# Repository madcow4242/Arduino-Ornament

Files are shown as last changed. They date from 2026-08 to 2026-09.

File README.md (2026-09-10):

# Arduino-powered Christmas Ornament (or badge, or anything else)

A custom LED Christmas ornament with advent calendar functionality, built using Arduino and KiCad.  This project can easily be adapted to other formats such as a badge by changing the PCB layout.  

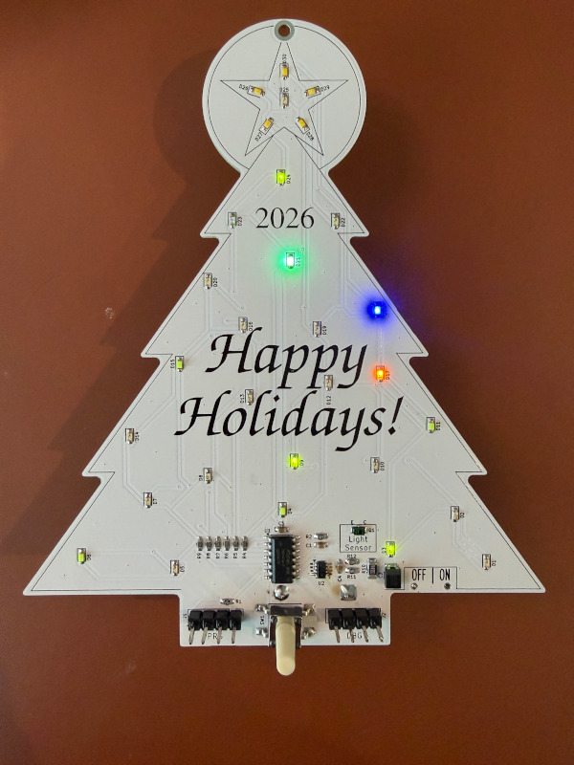
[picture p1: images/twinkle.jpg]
Example Ornament


### Key features:
- 30 individually-addressable LEDs
- PWM LED control, with support for up to 12 (or more) simultaneous LEDs
- Fade-in / Fade-out support
- Advent calendar mode included
- User-configurable advent date and brightness settings
- Light level measurement (optional)
- Current measurement via a precision 1-ohm current sense resistor and precision amplified ADC circuit (intended to help optimize power usage prior to software finalization) (optional)
- Optimized to fit within the 4k / 256 byte memory limitations of the ATTiny414, but is also compatible with larger variants such as the ATTiny 814/1614/824/1624/3224
- Production software is configured to run at 8MHz to optimize power usage (instead of default 20MHz) - this can be changed if higher PWM frequency is desired, for example.  (test software still runs at 20MHz)
- \>30 days run time on one set of 3x AAA batteries, using default Production software (5 hours/day on, with auto timer).  Can be run on other 3-5VDC power sources like CR2032 for shorter durations (however, \>3.5V is required for 2.8V LEDs or higher - so stick with ~2.2V LEDs or lower if using 3-3.3V power sources).

## Project Structure

This project is organized into three main directories:

### 1. KiCad Files (`KiCad_PCB_Ornament/`)
Contains all KiCad design files for the PCB:
- Schematic files (.kicad_sch)
- PCB layout files (.kicad_pcb)
- Component libraries (.lib, .dcm)
- Footprint files (.kicad_mod)
- Exported fabrication files (.gbr, .drl) (for the example design / messaging)

The PCB layout can be easily customized with your own text, or into a different physical format or size (like a badge) using KiCad - however if modifying the layout you'll have to re-route the board as well of course.  I chose to put the control electronics on the front of the board (to be geeky), but they could easily be moved to the back to clean up the appearance.

NOTE: the board design includes optional current monitoring circuit and light sensing circuit.  Neither of these are implemented in the production software, however they are fully functional and usable in the test software.  Those features can be ported to production as needed, or removed or unpopulated on the PCB.

### 2. Production Software (`Ornament_production_1/`)
The main firmware for the ornament controller:
- Main Arduino sketch (`Ornament_production_1.ino`)
- Configuration and constants
- LED control algorithms
- Date setting and brightness adjustment routines
- Software fits in under 4k of flash, and uses approx. 70 (of 256) bytes of dynamic storage

### 3. Test/Validation Software (`Ornament_test_1/`)
Code for testing and validating the PCB functionality:
- Calibration routines
- Basic functionality tests
- Hardware verification code
- Software uses less than the ATTiny414's 4k of flash and 256 bytes of dynamic storage
- Includes ADC routines for current monitoring and light level measurement, if needed (not used in production code)

## Production Features

- Advent calendar display (December 1-25)
- Custom LED patterns with twinkling effects, including PWM fade-in, fade-out
- Date setting via button interface
- Adjustable brightness levels (10% to 100%)
- Sleep/wake cycle automation
- Preview mode for manual activation during sleep, without affecting 24-hour auto-on timer

## Hardware Requirements

- Microchip ATtiny414 microcontroller (or others in that series)
- Custom PCB with LED matrix
- Power switch and button for user interface
- Battery or power supply for operation
- Optional serial monitor to view diagnostic output on the UART connections (test software only by default)

## Getting Started

1. Clone this repository
2. Open the KiCad project to view or modify the PCB design
3. Use the Arduino IDE to compile and upload the production firmware to the completed PCB
4. Test with the validation software to verify hardware functionality
5. Modify and install the production software as desired

## License

This project is licensed under the MIT License - see the LICENSE file for details.

## Notes

- Custom LCG (Linear Congruential Generator) for random number generation to save flash space
- Charlieplexing technique for LED control - it uses 6 GPIOs to allow individual addressability for up to 30 LEDs.
- PWM LED control for up to 12 LEDs simultaneously, using 3x 32-step groups for each PWM cycle (4 LEDs per cycle)
- (more LEDs can be controlled simultaneously via configuration, but will limit maximum LED brightness)

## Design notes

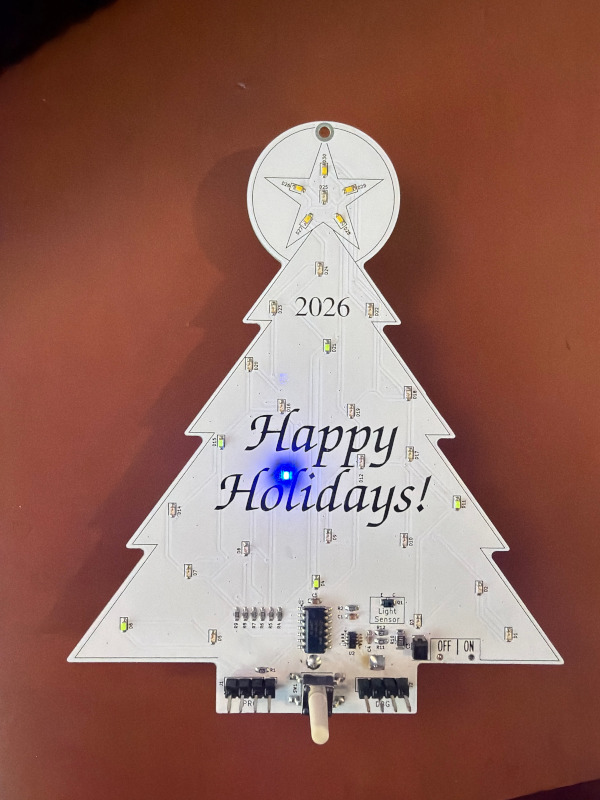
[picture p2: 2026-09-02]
images/adventday.jpg

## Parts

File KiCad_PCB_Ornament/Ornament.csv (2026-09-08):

Reference | Qty | Value | DNP | Exclude from BOM | Exclude from Board | Footprint | Datasheet | Mouser link | $ qty 1 | $ qty 25 | $ qty 100
BT1 | 1 | Battery_Holder |  |  |  | CustomLibrary:BatteryHolder_Keystone_2479_3xAAA-NoHoles | https://www.mouser.com/datasheet/3/201/1/2479.pdf | https://www.mouser.com/en/ProductDetail/Keystone-Electronics/2479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 | 1.8 | 1.6 | 1.58
C1 | 1 | C10nF |  |  |  | Capacitor_SMD:C_0603_1608Metric_Pad1.08x0.95mm_HandSolder | https://www.mouser.com/datasheet/3/72/1/C0603F103K9RACTU.pdf | https://www.mouser.com/en/ProductDetail/KEMET/C0603F103K9RACTU?qs=6avfeC6zeS4aPXDpR2QexA%3D%3D | 0.17 | 0.102 | 0.062
C3 | 1 | C220uF or 470uF low-ESR Polymer or Tantalum |  |  |  | Capacitor_SMD:C_1210_3225Metric_Pad1.33x2.70mm_HandSolder | https://www.mouser.com/datasheet/3/5926/1/TCJ.pdf | https://www.mouser.com/en/ProductDetail/KYOCERA-AVX/TCJB227M004R0060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 | 1.44 | 1 | 0.74
C4 | 1 | C1nF | Optional (Current Sense) |  |  | Capacitor_SMD:C_0603_1608Metric_Pad1.08x0.95mm_HandSolder | https://datasheets.kyocera-avx.com/AutoMLCC.pdf | https://www.mouser.com/en/ProductDetail/KYOCERA-AVX/06031F102K4T2A?qs=%252BdQmOuGyFcFZxL9GWikwcQ%3D%3D | 0.14 | 0.079 | 0.048
C5 | 1 | C1uF |  |  |  | Capacitor_SMD:C_0603_1608Metric_Pad1.08x0.95mm_HandSolder | https://ds.yuden.co.jp/TYCOMPAS/ut/download?pn=MSASE168SB5105KTNA01&fileType=CS | https://www.mouser.com/en/ProductDetail/TAIYO-YUDEN/MSASG168SB5105KTNA01?qs=yc9RBI4tIALTzUyUX1jaSQ%3D%3D | 0.17 | 0.073 | 0.042
D25 | 1 | LED - RED |  |  |  | LED_SMD:LED_0603_1608Metric_Pad1.05x0.95mm_HandSolder | https://www.mouser.com/datasheet/3/308/1/APG1608SURKC_T.pdf | https://www.mouser.com/en/ProductDetail/Kingbright/APG1608SURKC-T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 | 0.23 | 0.155 | 0.109
D26,D27,D28,D29,D30 | 5 | LED - WHITE |  |  |  | LED_SMD:LED_0603_1608Metric_Pad1.05x0.95mm_HandSolder | https://www.mouser.com/datasheet/3/5912/1/LW_Q38G_EN.pdf | https://www.mouser.com/en/ProductDetail/ams-OSRAM/LW-Q38G-Q2OO-3K5L-1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 | 0.58 | 0.35 | 0.139
D3,D9,D14,D19,D24 | 5 | LED - GREEN |  |  |  | LED_SMD:LED_0603_1608Metric_Pad1.05x0.95mm_HandSolder | https://www.mouser.com/datasheet/3/308/1/APG1608CGKC_T.pdf | https://www.mouser.com/en/ProductDetail/Kingbright/APG1608CGKC-T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 | 0.23 | 0.155 | 0.109
D2,D8,D13,D18,D23 | 5 | LED - BLUE |  |  |  | LED_SMD:LED_0603_1608Metric_Pad1.05x0.95mm_HandSolder | https://www.mouser.com/datasheet/3/308/1/APTD1608LVBC_D.pdf | https://www.mouser.com/en/ProductDetail/Kingbright/APTD1608LVBC-D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 | 0.58 | 0.408 | 0.294
D4,D6,D11,D15,D21 | 5 | LED - CYAN |  |  |  | LED_SMD:LED_0603_1608Metric_Pad1.05x0.95mm_HandSolder | https://www.mouser.com/datasheet/3/308/1/APT1608VRCXF_A_5MAV.pdf | https://www.mouser.com/en/ProductDetail/Kingbright/APT1608VRCXF-A-5MAV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 | 0.72 | 0.499 | 0.363
D1,D7,D12,D17,D22 | 5 | LED - YELLOW |  |  |  | LED_SMD:LED_0603_1608Metric_Pad1.05x0.95mm_HandSolder | https://www.mouser.com/datasheet/3/308/1/APG1608SYKC_T.pdf | https://www.mouser.com/en/ProductDetail/Kingbright/APG1608SYKC-T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 | 0.23 | 0.155 | 0.109
D5,D10,D16,D20 | 4 | LED - ORANGE |  |  |  | LED_SMD:LED_0603_1608Metric_Pad1.05x0.95mm_HandSolder | https://www.mouser.com/datasheet/3/308/1/APG1608SEKC_T.pdf | https://www.mouser.com/en/ProductDetail/Kingbright/APG1608SEKC-T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 | 0.23 | 0.155 | 0.109
H1 | 1 | MountingHole |  | Excluded from BOM |  | MountingHole:MountingHole_2.2mm_M2_DIN965_Pad_TopBottom | N/A | N/A
H2 | 1 | QR Code (silkscreen) |  | Excluded from BOM |  | CustomLibrary:15mmQR_cazabon_ornament | N/A | N/A
J1,J2 | 2 | Conn_01x04_Pin |  |  |  | Connector_PinHeader_2.54mm:PinHeader_1x04_P2.54mm_Vertical | https://cdn.amphenol-cs.com/media/wysiwyg/files/drawing/68000.pdf | https://www.mouser.com/en/ProductDetail/Amphenol-FCI/68004-404HLF?qs=iiM6sTJtPEeXIoTTLP40zg%3D%3D | 0.29 | 0.216 | 0.188
Q1 | 1 | TEMT6200FX01 | Optional (Light Sensor) |  |  | Resistor_SMD:R_0805_2012Metric_Pad1.20x1.40mm_HandSolder | https://www.rcscomponents.kiev.ua/datasheets/bpw40.pdf | https://www.mouser.com/en/ProductDetail/Vishay-Semiconductors/TEMT6200FX01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 | 0.76 | 0.643 | 0.614
R1 | 1 | R4.7k |  |  |  | Resistor_SMD:R_0603_1608Metric_Pad0.98x0.95mm_HandSolder | https://www.mouser.com/datasheet/3/508/1/PYu-RP_51_RoHS_L_3.pdf | https://www.mouser.com/en/ProductDetail/YAGEO/RP0603FRE074K7L?qs=Y0Uzf4wQF3kHfBhD8kHClQ%3D%3D | 0.1 | 0.049 | 0.047
R2 | 1 | R10k | Optional (Light Sensor) |  |  | Resistor_SMD:R_0603_1608Metric_Pad0.98x0.95mm_HandSolder | https://www.mouser.com/datasheet/3/72/1/PYU_RT_1_TO_0_01_ROHS_L.pdf | https://www.mouser.com/en/ProductDetail/YAGEO/RT0402FRE1310KL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 | 0.1 | 0.013 | 0.012
R4,R5,R6,R7,R8,R9 | 6 | R82 |  |  |  | Resistor_SMD:R_0603_1608Metric_Pad0.98x0.95mm_HandSolder | https://www.mouser.com/datasheet/3/72/1/PYU_RT_1_TO_0_01_ROHS_L.pdf | https://www.mouser.com/en/ProductDetail/YAGEO/RT0603BRD0782RL?qs=%2Ff7pOCXLR5eRsjR2nYqoNw%3D%3D | 0.1 | 0.06 | 0.056
R10 | 1 | R1 | R0 if no current sense |  |  | Resistor_SMD:R_1206_3216Metric | https://www.koaspeer.com/pdfs/SR73.pdf | https://www.mouser.com/en/ProductDetail/KOA-Speer/SR732BTTD1R00D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 | 0.53 | 0.228 | 0.205
R11,R12 | 2 | R100 | Optional (Current Sense) |  |  | Resistor_SMD:R_0603_1608Metric_Pad0.98x0.95mm_HandSolder | https://www.mouser.com/datasheet/3/508/1/PYU_RP_51_ROHS_L.pdf | https://www.mouser.com/en/ProductDetail/YAGEO/RP0603FRE07100RL?qs=Y0Uzf4wQF3lM9ZFwqInEig%3D%3D | 0.1 | 0.049 | 0.047
SW1 | 1 | SW_Push |  |  |  | Button_Switch_SMD:SW_Push_1P1T_NO_E-Switch_TL3301NxxxxxG | https://www.te.com/commerce/DocumentDelivery/DDEController?Action=srchrtrv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 | https://www.mouser.com/en/ProductDetail/TE-Connectivity-PB/1571563-6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 | 0.51 | 0.456 | 0.405
SW2 | 1 | SW_SPDT |  |  |  | Switch:CSS1210TB | https://www.nidec-copal-electronics.com/e/catalog/switch/css.pdf | https://www.mouser.com/en/ProductDetail/Nidec-Components/CSS-1210TB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 | 0.72 | 0.577 | 0.515
U1 | 1 | ATtiny414-SS (814,1614,424,824,1624,3224) |  |  |  | Package_SO:SOIC-14_3.9x8.7mm_P1.27mm | http://ww1.microchip.com/downloads/en/DeviceDoc/40001912A.pdf | https://www.mouser.com/en/ProductDetail/Microchip-Technology/ATTINY414-SSF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 | 0.68 | 0.62 | 0.619
U2 | 1 | INA190A3IDDFR | Optional (Current Sense) |  |  | Package_TO_SOT_SMD:SOT-23-8_Handsoldering | https://www.ti.com/lit/gpn/ina190 | https://www.mouser.com/en/ProductDetail/Texas-Instruments/INA190A3IDDFR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 | 2.34 | 1.59 | 1.42
 |  |  |  |  |  |  |  | BOM Cost | 24.92

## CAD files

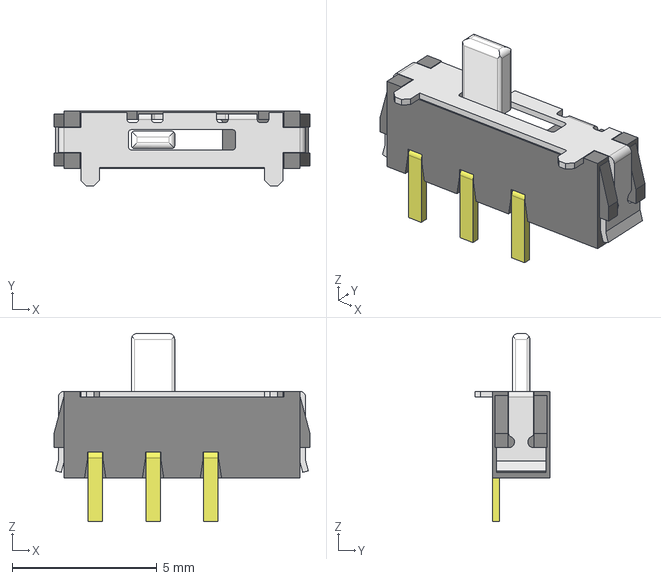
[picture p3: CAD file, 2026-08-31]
KiCad_PCB_Ornament/LIB_CSS-1210TB/CSS-1210TB/3D/CSS-1210TB.stp
8.85 x 2.60 x 6.50 mm
CSS-1210TB-b
CSS-1210TB-s

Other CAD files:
KiCad_PCB_Ornament/LIB_CSS-1210TB/CSS-1210TB/Allegro/css1210tb.psm
KiCad_PCB_Ornament/LIB_CSS-1210TB/CSS-1210TB/DEHDL/css_1210tb/chips/chips.prt

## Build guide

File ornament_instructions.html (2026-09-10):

# Ornament Controller Instructions

User Guide for the Custom LED Ornament

## Turning the Ornament On

1. Install 3x AAA batteries in the battery holder on the back of the ornament - with the negative (flat) side facing the spring in each compartment. (A fresh set of quality batteries should last ~30 days in normal operation with default brightness)

2. Locate the power switch on the right-hand side of the ornament, on the underside of the branches.

3. Slide the switch to the "on" position. Ideally, do this at the time you want the ornament to start its daily cycle.

4. The ornament will immediately begin operating in its default mode, alternating between "twinkling" and showing the advent calendar display.

5. The ornament will run for 5 hours from when you turned it on, then sleep until 24 hours after the initial powering-on and continue in that cycle. The result is that it will auto-activate at the same time each day, and run for 5 hours before going to sleep until the next day.

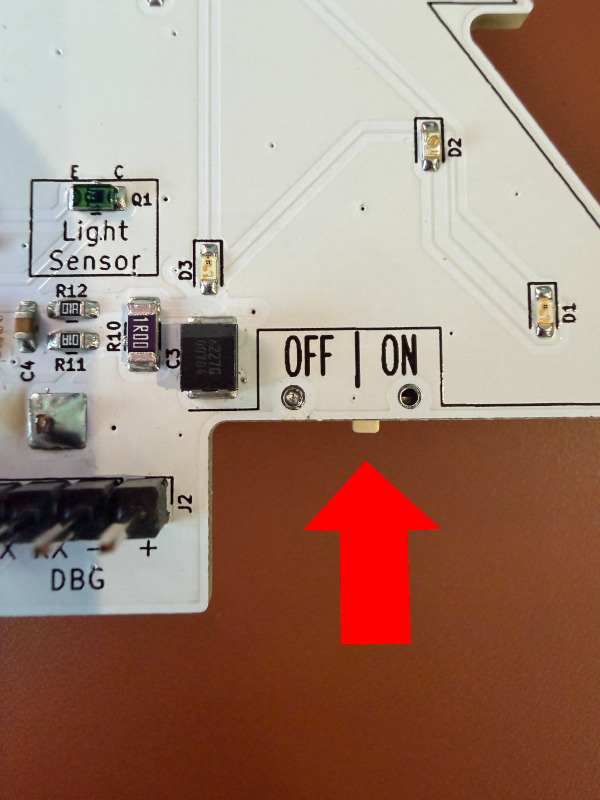
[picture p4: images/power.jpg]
Power Button Location


Figure 1: Power Button Location

## Setting the Daily Start Time

1. The ornament will automatically start each day at the same time, based on when you initially turn it on, or when power was most recently restored.

2. To set or re-set the start time, simply turn the ornament off by the switch (or remove the batteries), leave it off for at least 30 seconds, then turn it back on at the time you want it to start each day.

3. The ornament will now use this time as the daily start time.

4. There is no need to turn the ornament off or on each day - it will automatically cycle for 5 hours on daily, and will run for >30 days on a fresh set of AAA batteries.

5. Using the 'Preview Mode' (below) will not affect the daily start time.

## Setting the Date

When the ornament is first powered on, it presumes it is December 1st, and starts counting days from there. If you activate it on any other day, you can change the current date as below.

To get into setup mode:

1. Press and hold the button for 3 seconds until all the LEDs turn off.
2. When you release the button, the LED for the current day will blink.

To change the date:

1. Click the button once to advance the date by one day/LED.
2. Continue clicking to cycle through the days of December (1-25).
3. You can count the days with each click, or if you look VERY closely, each LED is numbered (D1 through D25, plus the star LEDs)
4. After 25, the ornament will wrap around and start at day 1 again.

Once you're on the correct LED for the day of the month:

- Wait 10 seconds, or press and hold the button for 2 seconds (then release) to continue to brightness setting mode

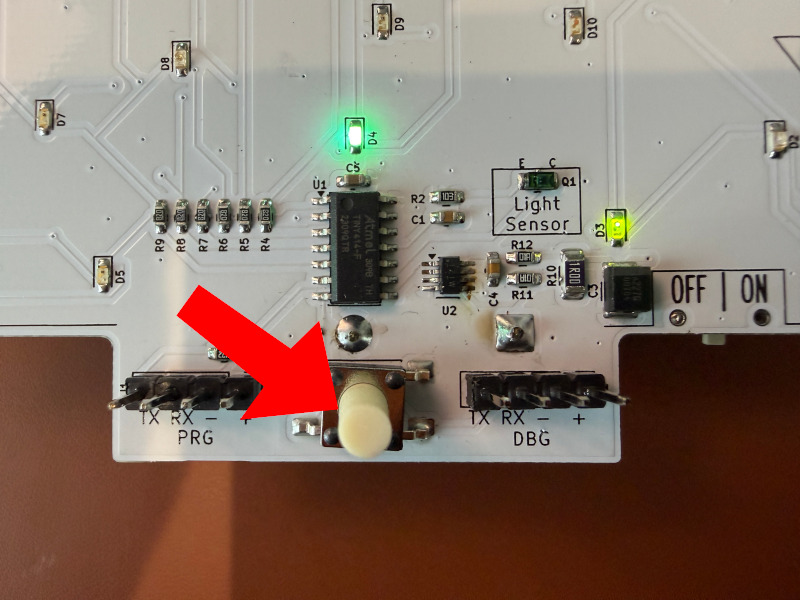
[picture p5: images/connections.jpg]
Date Setting Interface


Figure 2: Button for entering setup mode (advent day / brightness)

Note: The date setting process is designed to be intuitive and requires only a few simple button presses.

## Adjusting Brightness

To adjust the brightness level:

1. After setting the date as above, enter the brightness adjustment mode by pressing and holding the button for 2 seconds, or waiting 10 seconds as noted above.
2. One LED of each color will light up and start blinking at the current brightness setting. Note that this is peak brightness - and LEDs will normally appear slightly dimmer during regular operation because they fade in and fade out.
3. Press the button to cycle through the various brightness levels:
  - 10% - Dim setting
  - 25% - Low setting
  - 50% - Medium setting (default)
  - 75% - High setting
  - 100% - Maximum brightness
4. Once you're done, leave the ornament alone and it will save your settings after 10 seconds and return to normal operation, or you can press and hold the button for 2 seconds until the ornament resumes normal operation.

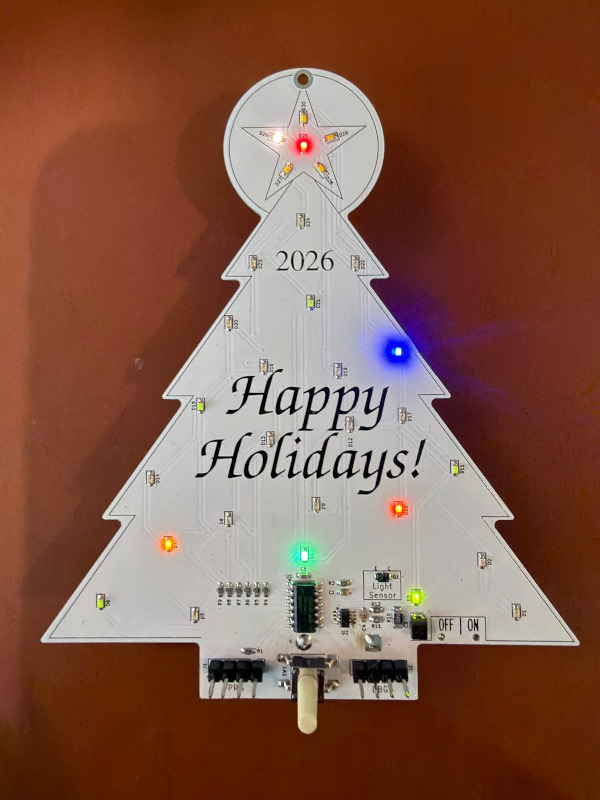
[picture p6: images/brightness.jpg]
Brightness Adjustment Interface


Figure 3: Brightness Adjustment Interface

Note: The date and brightness settings are saved and will persist after power-off.

## Normal Operation

The ornament has two alternating modes:

### Twinkle Mode

The ornament will display a twinkling pattern that cycles through different LED combinations for approximately 30 seconds, at the chosen brightness level.

Twinkle Mode Animation

Figure 4: Twinkle Mode Animation

### Advent Mode

Every 30 seconds, the ornament enters Advent mode where it displays a special pattern that progresses through the days of Advent:

1. Each day, a new LED pattern appears to indicate the current day of the Advent cycle
2. On the 25th day, it displays a special celebration pattern

Image: Advent Mode Animation

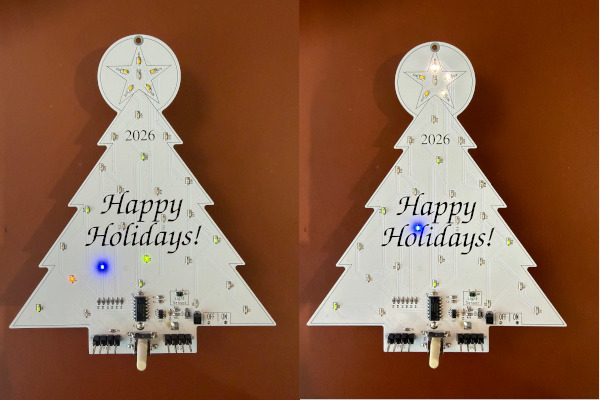
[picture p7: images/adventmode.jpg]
Advent Day Setting Interface


Figure 3: Advent Day Setting Interface

### Automatic Cycling and Sleep Mode

The ornament will turn on and run for 5 hours when you turn the power switch on the first time. It will automatically go into sleep mode after 5 hours, and turn back on again 24-hours from when you first turned it on - so that it will run at the same time each day without any user action.

To have it start at a different time each day, simply turn the ornament off by the switch, and turn it on at the time you'd like it to normally turn on by itself.

### Preview Mode

When the ornament is in sleep mode (no LEDs showing), pressing the button once will activate the ornament for 1 hour. This will not affect the normal auto-wake timing, and there should be ample battery power to do this many times over the Holiday Season without running out of battery.

## Troubleshooting

If the ornament is not responding as expected:

- Ensure the batteries are fresh, or replace with new batteries
- Try resetting the ornament by turning the power switch off, waiting at least 30 seconds, and then and back on
- Check that all connections are secure (battery)
- For timing issues, make sure to turn the ornament off and back on at your desired daily start time

## Hackers and Developers!

This project can be fully customized and modified by hackers and developers, and is fully open source.

- The PCB design files and full source code for the ATTiny414 microcontroller are available on GitHub: https://github.com/madcow4242/Arduino-Ornament
- Ornaments can be reprogrammed or customized via the "PRG" header on the board, using a standard UPDI programmer.

Ornament Controller v0.1.15 | Custom Arduino ATTiny414 controlled LED display

For technical support, please contact the kevin@cazabon.com

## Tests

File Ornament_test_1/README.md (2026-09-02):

# Ornament Test/Validation Software

This directory contains the test and validation software for the Ornament Controller project, used to verify hardware functionality and perform calibration procedures.

## Purpose and Features

The test software serves to:
- Verify PCB hardware functionality and LED matrix operation
- Measure current usage (baseline, full LED power, PWM LED power)
- Calibrate LED brightness and timing characteristics
- Test basic functionality including button response, current sensing, and light sensor operation
- Validate microcontroller operation

## Usage

### Setup
1. Connect the ornament PCB to your development environment
2. Load the `Ornament_test_1.ino` sketch into the Arduino IDE
3. Select the appropriate board (ATtiny414)
4. Upload the code to the microcontroller

### Test Modes
The test software automatically runs through various test sequences, advancing to the next test each time the button is pressed.  The tests included are, in order:
1. **LED Matrix Test**: Cycles through each LED to verify proper operation, while outputting power / current usage via UART.  It also displays the current light level from the light sensor.
2. **Brightness Calibration**: Tests different PWM levels to help choose the right calibration value.  Each LED cycles through all brightness levels starting at 31, down to 1, while displaying a calibrated reference LED at the same time.  The goal is to visually match the brightness of the test LED to the reference LED, so you can update the calibration table with the correct value.  Simply watch the blinking LED and count down from 31 until the brightness matches, and use that value in the calibration table.
3. **Pattern Verification**: Runs basic LED patterns to verify timing - illuminating up to 12 LEDs concurrently via PWM, and displaying fade-in-fade-out functionality.
4. **System Check**: Verifies button response and sleep/wake functionality

## Hardware Requirements

- Ornament PCB with ATtiny414 microcontroller
- USB-to-Serial adapter for programming
- Power source (Via programmer connection, UART connection, or battery)
- Serial monitor for test output (optional) - 9600 baud

## Troubleshooting

If tests fail:
1. Check all component connections
2. Verify power supply voltage (should be 3.3V to 5V)
3. Confirm correct board selection in Arduino IDE
4. Check for loose or damaged connections
5. Ensure proper grounding

## License

This project is licensed under the MIT License - see the LICENSE file for details.

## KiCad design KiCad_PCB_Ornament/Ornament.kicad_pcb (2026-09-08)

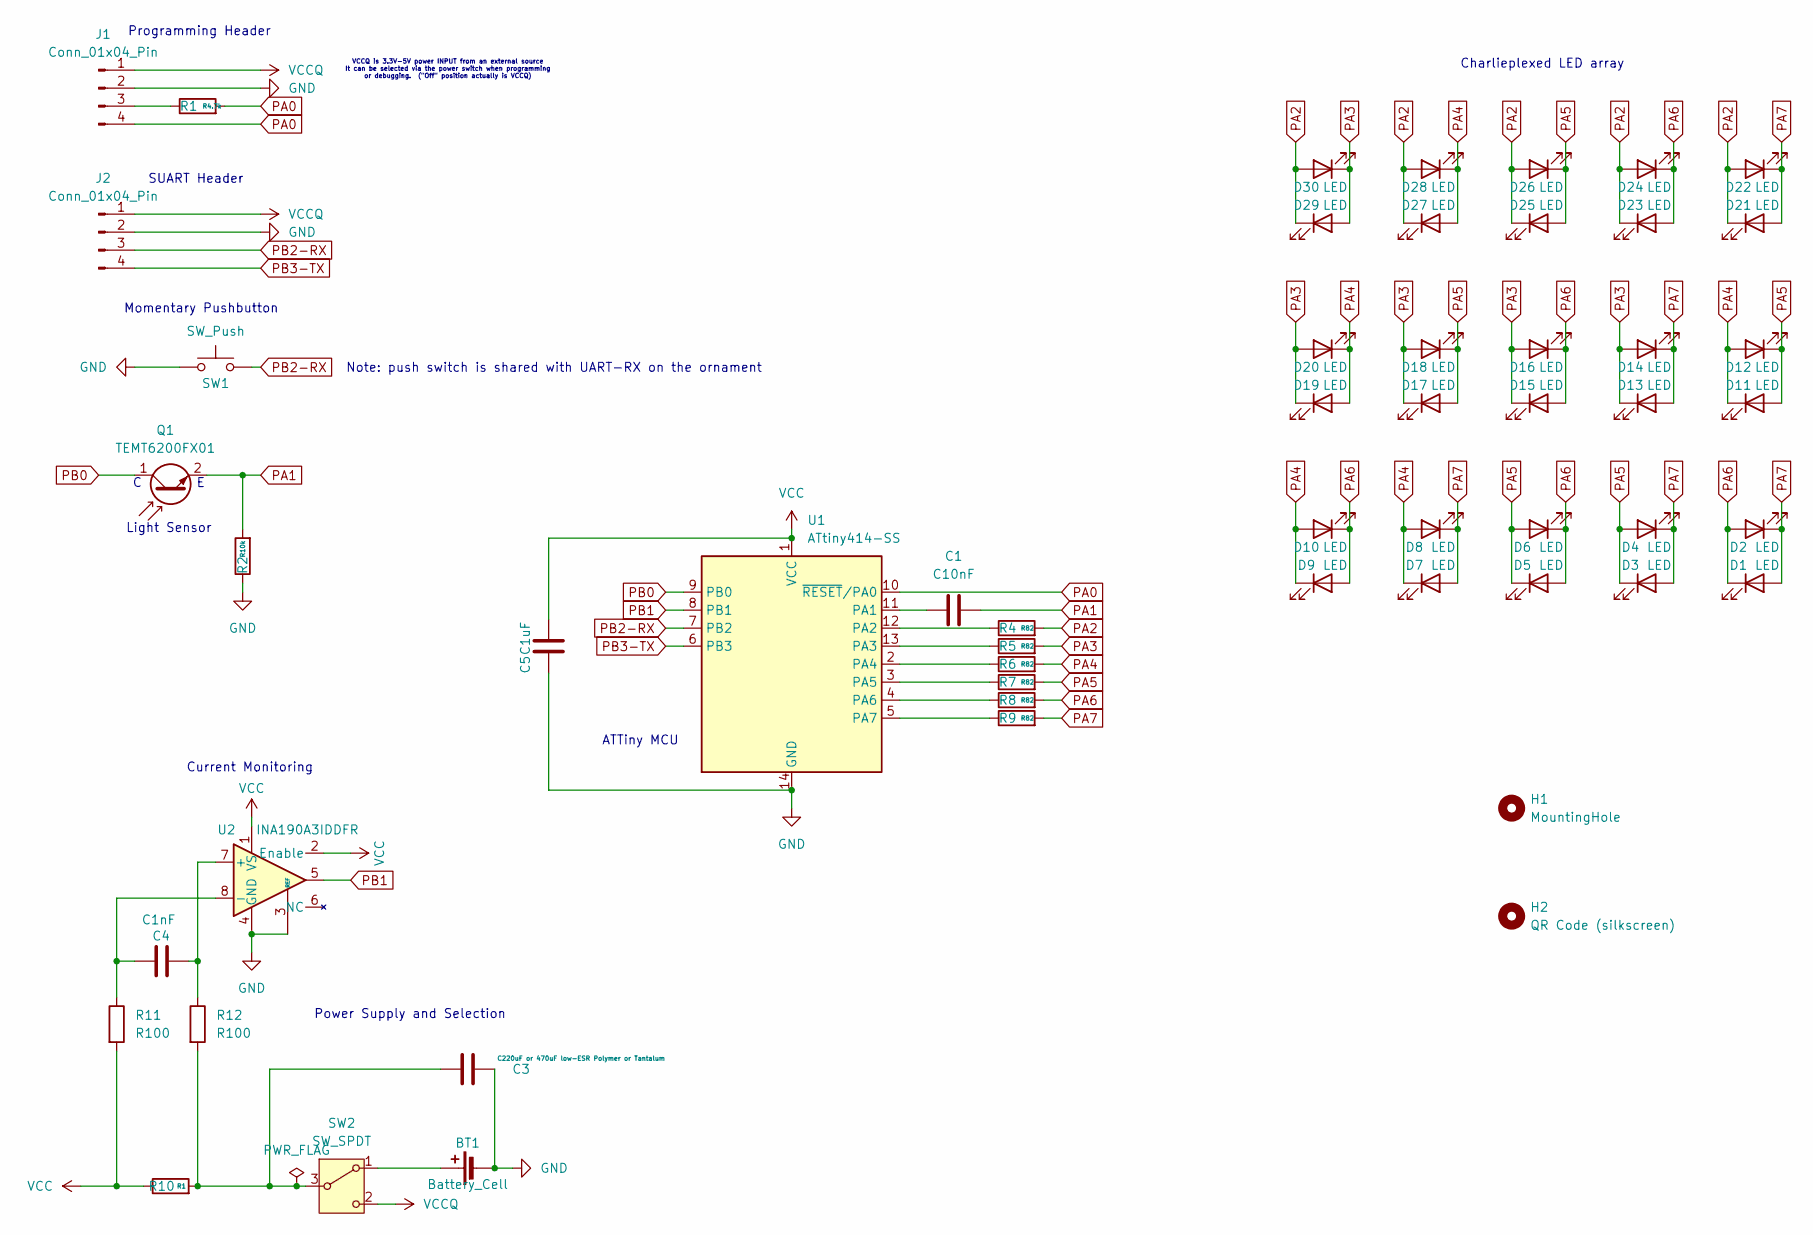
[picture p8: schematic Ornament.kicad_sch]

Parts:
BT1: Battery_Cell; BatteryHolder_Keystone_2479_3xAAA-NoHoles
C1: C10nF; C_0603_1608Metric_Pad1.08x0.95mm_HandSolder
C3: C220uF or 470uF low-ESR Polymer or Tantalum; C_1210_3225Metric_Pad1.33x2.70mm_HandSolder
C4: C1nF; C_0603_1608Metric_Pad1.08x0.95mm_HandSolder
C5: C1uF; C_0603_1608Metric_Pad1.08x0.95mm_HandSolder
D1, D2, D3, D4, D5, D6, D7, D8, D9, D10, D11, D12, D13, D14, D15, D16, D17, D18, D19, D20, D21, D22, D23, D24, D25, D26, D27, D28, D29, D30: LED; LED_0603_1608Metric_Pad1.05x0.95mm_HandSolder
H1: MountingHole; MountingHole_2.2mm_M2_DIN965_Pad_TopBottom
H2: QR Code (silkscreen); 15mmQR_cazabon_ornament
J1, J2: Conn_01x04_Pin; PinHeader_1x04_P2.54mm_Vertical
Q1: TEMT6200FX01; R_0805_2012Metric_Pad1.20x1.40mm_HandSolder
R1: R4.7k; R_0603_1608Metric_Pad0.98x0.95mm_HandSolder
R2: R10k; R_0603_1608Metric_Pad0.98x0.95mm_HandSolder
R4, R5, R6, R7, R8, R9: R82; R_0603_1608Metric_Pad0.98x0.95mm_HandSolder
R10: R1; R_1206_3216Metric
R11, R12: R100; R_0603_1608Metric_Pad0.98x0.95mm_HandSolder
SW1: SW_Push; SW_Push_1P1T_NO_E-Switch_TL3301NxxxxxG
SW2: SW_SPDT; CSS1210TB
U1: ATtiny414-SS; SOIC-14_3.9x8.7mm_P1.27mm
U2: INA190A3IDDFR; SOT-23-8_Handsoldering

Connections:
GND: BT1.2 (-), C3.1, C5.1, J1.2, J2.2, R2.1, SW1.1, U1.14 (GND), U2.3 (REF), U2.4 (GND)
unnamed: BT1.1 (+), SW2.1 (A)
unnamed: J1.3, R1.1
unnamed: C3.2, R10.2, R12.2, SW2.3 (B)
unnamed: C1.1, U1.11 (PA1)
unnamed: R4.1, U1.12 (PA2)
unnamed: R5.1, U1.13 (PA3)
unnamed: R6.1, U1.2 (PA4)
unnamed: R7.1, U1.3 (PA5)
unnamed: R8.1, U1.4 (PA6)
unnamed: R9.1, U1.5 (PA7)
unnamed: C4.2, R12.1, U2.7 (+)
unnamed: C4.1, R11.1, U2.8 (-)
PA0: J1.4, R1.2, U1.10 (~RESET/PA0)
PA1: C1.2, Q1.2 (E), R2.2
PA2: D21.1 (K), D22.2 (A), D23.1 (K), D24.2 (A), D25.1 (K), D26.2 (A), D27.1 (K), D28.2 (A), D29.1 (K), D30.2 (A), R4.2
PA3: D13.1 (K), D14.2 (A), D15.1 (K), D16.2 (A), D17.1 (K), D18.2 (A), D19.1 (K), D20.2 (A), D29.2 (A), D30.1 (K), R5.2
PA4: D7.1 (K), D8.2 (A), D9.1 (K), D10.2 (A), D11.1 (K), D12.2 (A), D19.2 (A), D20.1 (K), D27.2 (A), D28.1 (K), R6.2
PA5: D3.1 (K), D4.2 (A), D5.1 (K), D6.2 (A), D11.2 (A), D12.1 (K), D17.2 (A), D18.1 (K), D25.2 (A), D26.1 (K), R7.2
PA6: D1.1 (K), D2.2 (A), D5.2 (A), D6.1 (K), D9.2 (A), D10.1 (K), D15.2 (A), D16.1 (K), D23.2 (A), D24.1 (K), R8.2
PA7: D1.2 (A), D2.1 (K), D3.2 (A), D4.1 (K), D7.2 (A), D8.1 (K), D13.2 (A), D14.1 (K), D21.2 (A), D22.1 (K), R9.2
PB0: Q1.1 (C), U1.9 (PB0)
PB1: U1.8 (PB1), U2.5
PB2-RX: J2.3, SW1.2, U1.7 (PB2)
PB3-TX: J2.4, U1.6 (PB3)
VCC: C5.2, R10.1, R11.2, U1.1 (VCC), U2.1 (VS), U2.2 (Enable)
VCCQ: J1.1, J2.1, SW2.2 (C)

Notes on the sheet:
Programming Header
Current Monitoring
Power Supply and Selection
Light Sensor
VCCQ is 3.3V-5V power INPUT from an external source It can be selected via the power switch when programming or debugging. ("Off" position actually is VCCQ)
Note: push switch is shared with UART-RX on the ornament
ATTiny MCU
Charlieplexed LED array
Momentary Pushbutton
C E
SUART Header

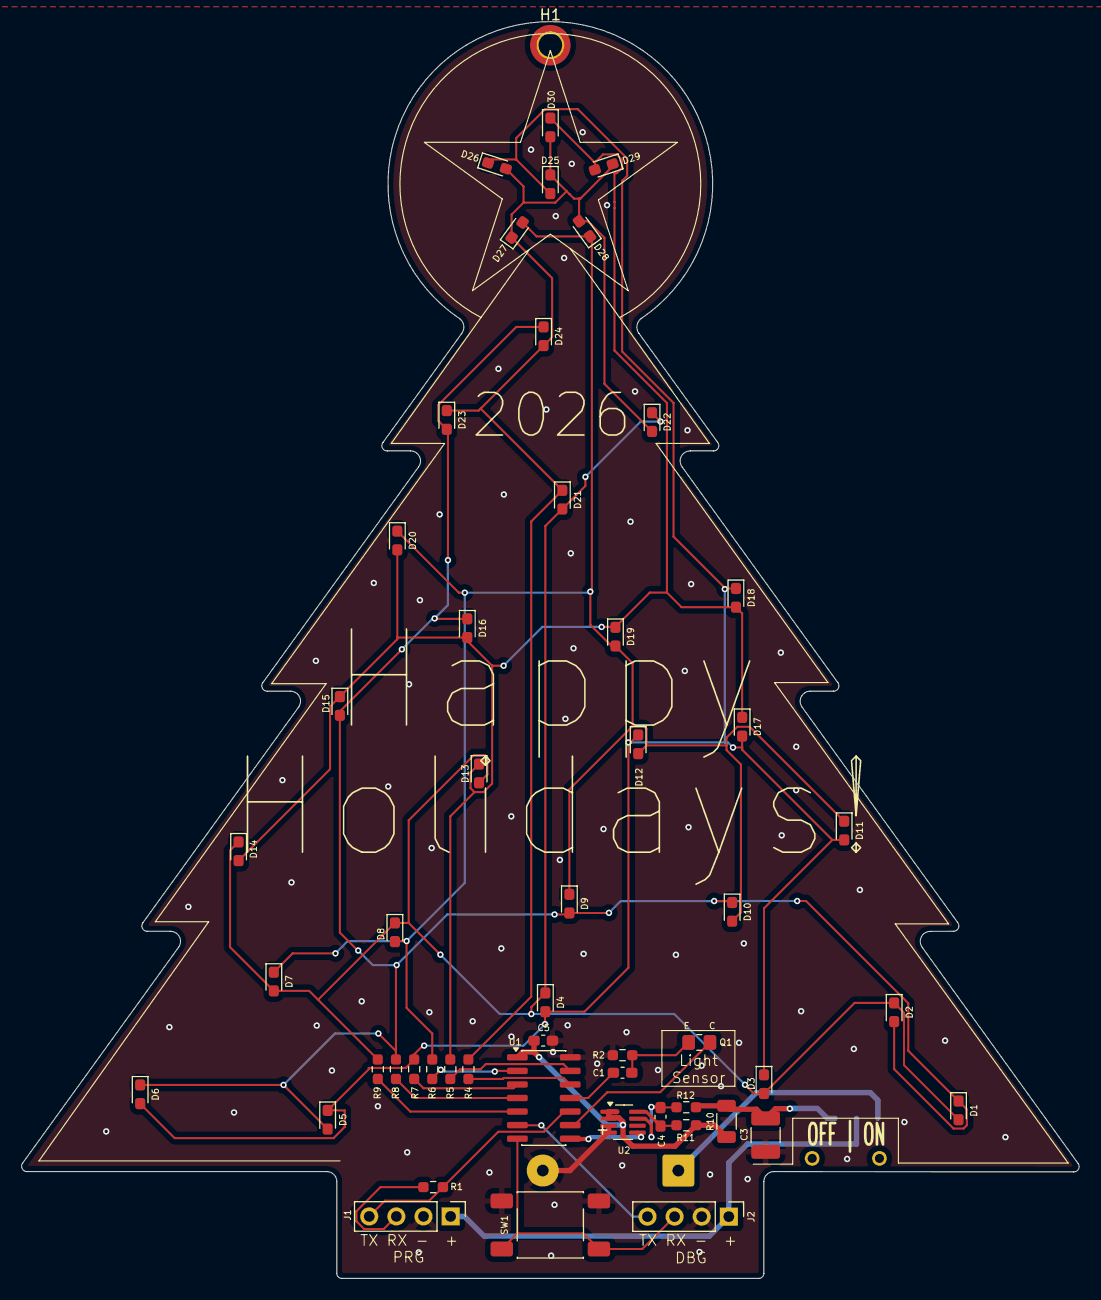
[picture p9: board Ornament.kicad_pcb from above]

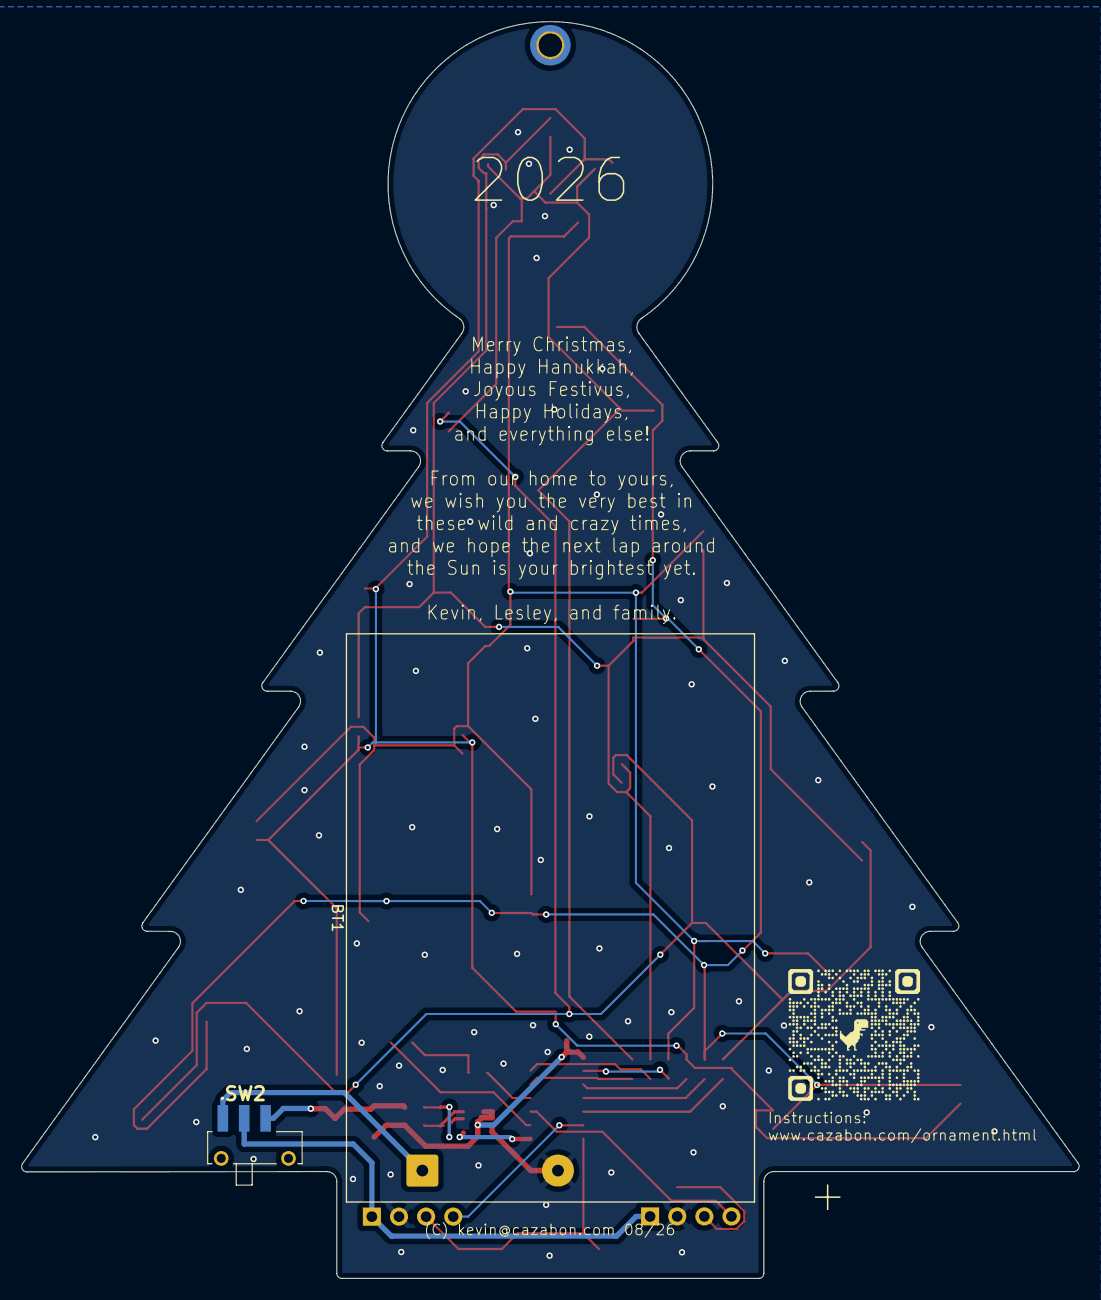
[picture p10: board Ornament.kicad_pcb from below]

Board: 2 copper layers, 99.0 x 117.7 mm, 55 parts (3 on the bottom side), 27 nets.

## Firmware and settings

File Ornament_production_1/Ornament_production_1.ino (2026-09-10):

// ============================================================================
// Ornament Controller - Production Software (v0.1.6)
// Target Hardware: Microchip ATtiny414/814/1614 (tinyAVR 1-Series)
// This software is designed to control a 30-LED Charlieplexed display for an ornament, with various lighting effects and user interaction via a button.
// (C) Kevin Cazabon, 2026 kevin@cazabon.com / http://www.github.com/madcow4242/Arduino-Ornament 
// Licensed under the MIT License (https://opensource.org/licenses/MIT) - contact kevin@cazabon.com for more information or commercial licensing.
// ============================================================================
#include <Arduino.h>
#include <avr/io.h>
#include <avr/interrupt.h>
#include <avr/eeprom.h>
#include <avr/sleep.h>
#include <util/delay.h>

#define PWM_MAX 32                  
#define GROUP_CYCLE_MS 1000
#define MAX_GROUP_LEDS 4            
#define NUM_GROUPS 3   
         
#define FULL_CYCLE_MS    86400000UL     // 24 hours
#define RUNTIME_LIMIT_MS 18000000UL     // 5 hours    
#define PREVIEW_LIMIT_MS 3600000UL      // 1 hour

#define TWINKLE_DUR_MS      30000
#define ADVENT_RACE_STEP_MS 200     
#define STAR_CHASE_STEP_MS  150      
#define ADVENT_PULSE_MS     6000

typedef struct { int8_t hi; int8_t lo; } LEDMap;
typedef struct { uint8_t num; uint8_t level; } LEDPair;

static LEDPair groups[NUM_GROUPS][MAX_GROUP_LEDS];

EEMEM uint8_t ee_advent_day = 1;
EEMEM uint8_t ee_global_brightness = 50;

volatile uint8_t enter_date_set = 0;
static uint8_t global_brightness_level = 50;

static uint8_t rng_state = 42;

static uint8_t fast_rand(void) {
    rng_state ^= (uint8_t)millis(); // Inject live entropy from the system timer
    uint8_t x = rng_state;
    x ^= x << 3;
    x ^= x >> 5;
    x ^= x << 4;
    rng_state = x;
    return x;
}

static uint8_t scale_pwm_val(uint8_t lvl, uint8_t cal) {
    uint16_t l = ((uint16_t)lvl * cal) >> 5; 
    l = (l * global_brightness_level) / 50;
    if (l == 0 && lvl) l = 1;
    return l > PWM_MAX ? PWM_MAX : l;
}

const uint8_t calibration_table[30] PROGMEM = {
    14, 14, 30, 7, 10, 7, 14, 14, 30, 10,     
    7, 14, 14, 30, 7, 10, 14, 14, 30, 10,     
    7, 14, 14, 30, 18, 9, 9, 9, 9, 9          
};

const uint8_t led_pin_masks[] = {0x04, 0x08, 0x10, 0x20, 0x40, 0x80}; 

const LEDMap charlie_map[30] PROGMEM = {
    {5,4}, {4,5}, {5,3}, {3,5}, {4,3}, {3,4}, {5,2}, {2,5}, {4,2}, {2,4}, 
    {3,2}, {2,3}, {5,1}, {1,5}, {4,1}, {1,4}, {3,1}, {1,3}, {2,1}, {1,2}, 
    {5,0}, {0,5}, {4,0}, {0,4}, {3,0}, {0,3}, {2,0}, {0,2}, {1,0}, {0,1}  
};

const uint8_t brightness_preview_leds[] PROGMEM = {3, 25, 4, 18, 10, 7, 26};

// Button press interrupt service routine - triggered on falling edge of button pin (PB2)
ISR(PORTB_PORT_vect) {
    PORTB.INTFLAGS = PIN2_bm;
}

void check_button() {
    static uint32_t press_start;
    static uint8_t tracking;

    if (!(PORTB.IN & PIN2_bm)) { 
        if (!tracking) {
            press_start = millis();
            tracking = 1;
        } else if (tracking == 1 && (millis() - press_start >= 3000)) {
            enter_date_set = 1;
            tracking = 2; 
        }
    } else {
        tracking = 0; 
    }
}

void set_hardware_led(uint8_t num) {
    PORTA.DIRCLR = 0xFC; 
    PORTA.OUTCLR = 0xFC; 
    if (num < 1 || num > 30) return; 
    uint8_t idx = num - 1;
    uint8_t hi = pgm_read_byte(&charlie_map[idx].hi);
    uint8_t lo = pgm_read_byte(&charlie_map[idx].lo);
    PORTA.DIRSET = led_pin_masks[hi] | led_pin_masks[lo]; 
    PORTA.OUTSET = led_pin_masks[hi]; 
}

uint8_t leds_share_pins(uint8_t led1, uint8_t led2) {
    if (led1 < 1 || led1 > 30 || led2 < 1 || led2 > 30) return 1;
    int8_t h1 = pgm_read_byte(&charlie_map[led1 - 1].hi);
    int8_t l1 = pgm_read_byte(&charlie_map[led1 - 1].lo);
    int8_t h2 = pgm_read_byte(&charlie_map[led2 - 1].hi);
    int8_t l2 = pgm_read_byte(&charlie_map[led2 - 1].lo);
    return (h1 == h2 || h1 == l2 || l1 == h2 || l1 == l2);
}

uint8_t select_single_channel_leds(LEDPair channel_leds[MAX_GROUP_LEDS], uint8_t advent_day) {
    uint8_t count = 0, attempts = 0;
    uint8_t target = (fast_rand() & (MAX_GROUP_LEDS - 1)) + 1;

    while (count < target && attempts < 25) {
        uint8_t led = (fast_rand() & 0x1F) + 1;
        if (led > 30 || (led == 25 && advent_day != 25)) { attempts++; continue; }

        uint8_t conflict = 0;
        for (uint8_t i = 0; i < count; i++) {
            if (leds_share_pins(led, channel_leds[i].num)) { conflict = 1; break; }
        }

        if (!conflict) {
            uint8_t cal = pgm_read_byte(&calibration_table[led - 1]);
            channel_leds[count].num = led;
            channel_leds[count].level = scale_pwm_val(PWM_MAX, cal);
            count++;
            attempts = 0;
        } else {
            attempts++;
        }
    }
    return count;
}

void output_leds_common(const uint8_t active_counts[NUM_GROUPS]) {
    uint32_t frame_start = millis();
    while ((millis() - frame_start) < 5) {
        if (enter_date_set) return;
        for (uint8_t g = 0; g < NUM_GROUPS; g++) {
            uint8_t count = active_counts[g];
            uint8_t total_active_units = 0;
            for (uint8_t i = 0; i < count; i++) {
                if (groups[g][i].level > 0) {
                    total_active_units += groups[g][i].level;
                }
            }
            uint8_t off_units = (total_active_units < PWM_MAX) ? (PWM_MAX - total_active_units) : 0;

            for (uint8_t i = 0; i < count; i++) {
                uint8_t lvl = groups[g][i].level;
                if (lvl > 0) {
                    set_hardware_led(groups[g][i].num);
                    for (uint8_t l = 0; l < lvl; l++) _delay_us(20);
                }
            }
            set_hardware_led(0);
            for (uint8_t l = 0; l < off_units; l++) _delay_us(20);
        }
    }
}

void twinkle(uint32_t duration_ms, uint8_t advent_day) {
    static LEDPair base_groups[NUM_GROUPS][MAX_GROUP_LEDS];
    uint8_t group_counts[NUM_GROUPS] = {0};
    uint32_t group_start_times[NUM_GROUPS];
    uint32_t start_time = millis();
    uint32_t stagger = GROUP_CYCLE_MS / NUM_GROUPS;

    for (uint8_t g = 0; g < NUM_GROUPS; g++) {
        group_start_times[g] = start_time + (g * stagger);
    }
    
    while (!enter_date_set) {
        uint32_t now = millis();
        if ((now - start_time >= duration_ms)) {
            uint8_t active_total = 0;
            for (uint8_t g = 0; g < NUM_GROUPS; g++) {
                if (group_counts[g] > 0 && (now - group_start_times[g] < GROUP_CYCLE_MS)) {
                    active_total++;
                }
            }
            if (active_total == 0) break;
        }

        check_button(); 
        if (enter_date_set) return;

        uint8_t active_counts[NUM_GROUPS] = {0};

        for (uint8_t g = 0; g < NUM_GROUPS; g++) {
            if (now < group_start_times[g]) continue;

            uint32_t elapsed = now - group_start_times[g];
            if (elapsed >= GROUP_CYCLE_MS) {
                if (now - start_time < duration_ms) {
                    group_start_times[g] += GROUP_CYCLE_MS;
                    elapsed = now - group_start_times[g];
                    group_counts[g] = select_single_channel_leds(base_groups[g], advent_day);
                    if (group_counts[g] == 0) group_counts[g] = 1;
                } else {
                    group_counts[g] = 0;
                    continue;
                }
            } else if (group_counts[g] == 0) {
                group_counts[g] = select_single_channel_leds(base_groups[g], advent_day);
                if (group_counts[g] == 0) group_counts[g] = 1;
            }

            uint16_t progress_permille = (elapsed * 1000) / GROUP_CYCLE_MS;
            if (progress_permille > 1000) progress_permille = 1000; 

            uint8_t current_pwm_level = (progress_permille <= 500)
                ? (progress_permille * PWM_MAX) / 500
                : PWM_MAX - (((progress_permille - 500) * PWM_MAX) / 500);

            active_counts[g] = group_counts[g];
            for (uint8_t i = 0; i < group_counts[g]; i++) {
                uint8_t num = base_groups[g][i].num;
                groups[g][i].num = num;
                uint8_t cal = pgm_read_byte(&calibration_table[num - 1]);
                groups[g][i].level = scale_pwm_val(current_pwm_level, cal);
            }
        }
        output_leds_common(active_counts);
    }
}

void advent_single_round(uint8_t advent_day) {
    for (uint8_t current_led = 1; current_led < advent_day && !enter_date_set; current_led++) {
        uint32_t step_start = millis();
        while ((millis() - step_start) < ADVENT_RACE_STEP_MS && !enter_date_set) {
            check_button(); 
            if (enter_date_set) return;

            uint16_t elapsed = millis() - step_start;
            uint16_t progress = (elapsed * 1000) / ADVENT_RACE_STEP_MS;
            
            uint8_t lead_pwm = (progress <= 500) ? (progress * PWM_MAX) / 500 : PWM_MAX - (((progress - 500) * PWM_MAX) / 500);
            groups[0][0].num = current_led;
            groups[0][0].level = scale_pwm_val(lead_pwm, pgm_read_byte(&calibration_table[current_led - 1]));

            uint8_t count = 1;
            if (current_led > 1) {
                groups[0][1].num = current_led - 1;
                groups[0][1].level = scale_pwm_val((PWM_MAX / 2) - ((progress * (PWM_MAX / 2)) / 1000), pgm_read_byte(&calibration_table[current_led - 2]));
                count++;
            }
            if (current_led > 2) {
                groups[0][2].num = current_led - 2;
                groups[0][2].level = scale_pwm_val((PWM_MAX / 5) - ((progress * (PWM_MAX / 5)) / 1000), pgm_read_byte(&calibration_table[current_led - 3]));
                count++;
            }
            uint8_t counts[NUM_GROUPS] = {count, 0, 0};
            output_leds_common(counts);
        }
    }

    uint32_t phase2_start = millis();
    while ((millis() - phase2_start) < ((uint32_t)ADVENT_PULSE_MS) && !enter_date_set) {
        check_button(); 
        if (enter_date_set) return;

        uint32_t elapsed = millis() - phase2_start;
        uint16_t rem = elapsed % 1000;
        uint8_t pulse_pwm = (rem <= 500) ? (rem * PWM_MAX) / 500 : PWM_MAX - (((rem - 500) * PWM_MAX) / 500);

        groups[0][0].num = advent_day;
        groups[0][0].level = scale_pwm_val(pulse_pwm, pgm_read_byte(&calibration_table[advent_day - 1]));

        uint16_t step_index = elapsed / STAR_CHASE_STEP_MS;
        uint16_t step_progress = ((elapsed % STAR_CHASE_STEP_MS) * 1000) / STAR_CHASE_STEP_MS;

        groups[1][0].num = 26 + (step_index % 5);
        groups[1][0].level = scale_pwm_val(PWM_MAX, pgm_read_byte(&calibration_table[groups[1][0].num - 1]));

        groups[1][1].num = 26 + ((step_index + 4) % 5);
        groups[1][1].level = scale_pwm_val((PWM_MAX / 2) - ((step_progress * (PWM_MAX / 2)) / 1000), pgm_read_byte(&calibration_table[groups[1][1].num - 1]));

        groups[1][2].num = 26 + ((step_index + 3) % 5);
        groups[1][2].level = scale_pwm_val((PWM_MAX / 5) - ((step_progress * (PWM_MAX / 5)) / 1000), pgm_read_byte(&calibration_table[groups[1][2].num - 1]));

        uint8_t counts[NUM_GROUPS] = {1, 3, 0};
        output_leds_common(counts);
    }
}

void handle_date_setting(uint8_t* current_day) {
    enter_date_set = 0;
    uint32_t inactivity_timer, blink_timer;
    uint8_t led_state = 1;

    while (!(PORTB.IN & PIN2_bm));
    _delay_ms(50); 

    inactivity_timer = blink_timer = millis(); 
    while (millis() - inactivity_timer < 10000) {
        if (!(PORTB.IN & PIN2_bm)) {
            uint32_t press_time = millis();
            while (!(PORTB.IN & PIN2_bm)) {
                if (millis() - press_time >= 1000) goto save_day;
            }
            _delay_ms(30); 
            if (++(*current_day) > 25) *current_day = 1;
            inactivity_timer = blink_timer = millis(); 
            led_state = 1;
            _delay_ms(50);
        }
        if (millis() - blink_timer >= 300) { led_state = !led_state; blink_timer = millis(); }

        uint8_t counts[NUM_GROUPS] = {0, 0, 0};
        if (led_state) {
            groups[0][0].num = *current_day;
            groups[0][0].level = scale_pwm_val(PWM_MAX, pgm_read_byte(&calibration_table[*current_day - 1]));
            counts[0] = 1;
        }
        output_leds_common(counts);
    }
save_day:
    eeprom_update_byte(&ee_advent_day, *current_day);
    set_hardware_led(0);
    _delay_ms(300);

    inactivity_timer = blink_timer = millis();
    led_state = 1;

    while (millis() - inactivity_timer < 10000) {
        if (!(PORTB.IN & PIN2_bm)) {
            uint32_t press_time = millis();
            while (!(PORTB.IN & PIN2_bm)) {
                if (millis() - press_time >= 1000) goto save_brightness;
            }
            _delay_ms(30);
            
            global_brightness_level = (global_brightness_level >= 100) ? 10 : global_brightness_level + 25;
            if (global_brightness_level == 35) global_brightness_level = 50; 

            inactivity_timer = blink_timer = millis();
            led_state = 1;
            _delay_ms(50);
        }
        if (millis() - blink_timer >= 300) { led_state = !led_state; blink_timer = millis(); }

        uint8_t counts[NUM_GROUPS] = {0, 0, 0};
        if (led_state) {
            for (uint8_t i = 0; i < 4; i++) {
                uint8_t led = pgm_read_byte(&brightness_preview_leds[i]);
                groups[0][i].num = led;
                groups[0][i].level = scale_pwm_val(PWM_MAX, pgm_read_byte(&calibration_table[led - 1]));
            }
            for (uint8_t i = 0; i < 3; i++) {
                uint8_t led = pgm_read_byte(&brightness_preview_leds[4 + i]);
                groups[1][i].num = led;
                groups[1][i].level = scale_pwm_val(PWM_MAX, pgm_read_byte(&calibration_table[led - 1]));
            }
            counts[0] = 4; counts[1] = 3; counts[2] = 0;
        }
        output_leds_common(counts);
    }

save_brightness:
    eeprom_update_byte(&ee_global_brightness, global_brightness_level);
    set_hardware_led(0);
    enter_date_set = 0;
    _delay_ms(250);
}

void rtc_init(void) {
    while (RTC.STATUS > 0) { ; }
    RTC.CLKSEL = RTC_CLKSEL_INT32K_gc; 
    RTC.PITCTRLA = RTC_PERIOD_CYC32768_gc | RTC_PITEN_bm; 
}

ISR(RTC_PIT_vect) {
    RTC.PITINTFLAGS = RTC_PI_bm; 
}

void execute_show(uint8_t day) {
    twinkle(TWINKLE_DUR_MS, day);
    if (!enter_date_set) advent_single_round(day);
}

int main(void) {
    _PROTECTED_WRITE(CLKCTRL.MCLKCTRLB, 0x00);
    init();
    rtc_init();

    _PROTECTED_WRITE(CLKCTRL.MCLKCTRLB, CLKCTRL_PDIV_2X_gc | CLKCTRL_PEN_bm); 
   
    ADC0.CTRLA &= ~ADC_ENABLE_bm; 
    PORTA.PIN0CTRL = PORT_ISC_INPUT_DISABLE_gc;
    PORTA.PIN1CTRL = PORT_ISC_INPUT_DISABLE_gc;
    PORTB.PIN0CTRL = PORT_ISC_INPUT_DISABLE_gc;
    PORTB.PIN1CTRL = PORT_ISC_INPUT_DISABLE_gc;

    PORTB.DIRSET = PIN3_bm; 
    PORTB.OUTSET = PIN3_bm; 
    PORTA.PIN3CTRL = PORT_ISC_INPUT_DISABLE_gc; 
    PORTB.DIRCLR = PIN2_bm;         
    PORTB.PIN2CTRL = PORT_PULLUPEN_bm | PORT_ISC_FALLING_gc; 

    sei(); 

    rng_state ^= (uint8_t)millis();
    if (rng_state == 0) rng_state = 42;

    uint8_t current_advent_day = eeprom_read_byte(&ee_advent_day);
    if (current_advent_day < 1 || current_advent_day > 25) {
        current_advent_day = 1;
        eeprom_update_byte(&ee_advent_day, current_advent_day);
    }

    uint8_t stored_brightness = eeprom_read_byte(&ee_global_brightness);
    if (stored_brightness >= 10 && stored_brightness <= 100) {
        global_brightness_level = stored_brightness;
    } else {
        global_brightness_level = 50;
        eeprom_update_byte(&ee_global_brightness, global_brightness_level);
    }

    while (1) {
        check_button();
        if (enter_date_set) {
            handle_date_setting(&current_advent_day);
            continue;
        }

        PORTB.DIRSET = PIN3_bm; 
        PORTB.OUTSET = PIN3_bm; 

        uint32_t run_start_ms = millis();

        while ((millis() - run_start_ms < RUNTIME_LIMIT_MS) && !enter_date_set) {
            execute_show(current_advent_day);
        }

        if (!enter_date_set) {
            if (++current_advent_day > 25) current_advent_day = 1;
            eeprom_update_byte(&ee_advent_day, current_advent_day);
        } else {
            continue;
        }
        
        set_hardware_led(0);
        PORTB.OUTCLR = PIN3_bm; 
        set_sleep_mode(SLEEP_MODE_PWR_DOWN);
        
        uint32_t remaining_sleep_ms = FULL_CYCLE_MS - (millis() - run_start_ms);
        RTC.PITINTCTRL = RTC_PI_bm; 
        
        while (remaining_sleep_ms > 0) {
            sleep_mode(); 
            
            if (!(PORTB.IN & PIN2_bm)) {
                RTC.PITINTCTRL = 0; 
                
                PORTB.DIRSET = PIN3_bm; 
                PORTB.OUTSET = PIN3_bm; 

                uint32_t preview_start = millis();
                while ((millis() - preview_start < PREVIEW_LIMIT_MS) && !enter_date_set) {
                    execute_show(current_advent_day);
                }
                set_hardware_led(0);
                PORTB.OUTCLR = PIN3_bm; 
                while (!(PORTB.IN & PIN2_bm));
                _delay_ms(50);
                
                if (enter_date_set) break; 

                remaining_sleep_ms = FULL_CYCLE_MS - (millis() - run_start_ms);
                RTC.PITINTCTRL = RTC_PI_bm; 
            } else {
                if (remaining_sleep_ms > 1000) {
                    remaining_sleep_ms -= 1000;
                } else {
                    remaining_sleep_ms = 0;
                }
            }
        }
        RTC.PITINTCTRL = 0;
    }
}

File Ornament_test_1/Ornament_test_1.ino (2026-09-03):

// ============================================================================
// Ornament Controller - Test and Calibration Routine (v0.6.4)
// Target Hardware: Microchip ATtiny414 (tinyAVR 1-Series)
// ============================================================================

#include <Arduino.h>
#include <avr/io.h>
#include <avr/interrupt.h>
#include <util/delay.h>
#include <stdlib.h>

#define PWM_MAX 32                  

#define MODE0_ON_TIME_MS 300
#define MODE0_OFF_TIME_MS 100

#define LED_ON_TIME_MS 300  
#define LEVEL_DELAY_MS 75    
      
#define MAX_GROUP_LEDS 4           
#define NUM_GROUPS 3               

#define GROUP_CYCLE_MS 1000

#define ENABLE_CSA_READINGS 1   

#define GLOBAL_BRIGHTNESS_LEVEL 70

typedef struct {
    int8_t hi; 
    int8_t lo; 
} LEDMap;

typedef struct {
    uint8_t num;    
    uint8_t level; 
} LEDPair;

static inline uint8_t scale_pwm_val(uint32_t lvl, uint8_t cal) {
    uint32_t l = (lvl * cal) / PWM_MAX;
    l = (l * GLOBAL_BRIGHTNESS_LEVEL) / 50;
    if (l == 0 && lvl > 0) l = 1;
    if (l > PWM_MAX) l = PWM_MAX;
    return (uint8_t)l;
}

const uint8_t calibration_table[30] = {
    14, 14, 30, 7, 10, 7, 14, 14, 30, 10,     
    7, 14, 14, 30, 7, 10, 14, 14, 30, 10,     
    7, 14, 14, 30, 18, 9, 9, 9, 9, 9          
};

const uint8_t reference_leds[] = {3, 9, 14, 19, 24};    
const uint8_t led_pin_masks[] = {0x04, 0x08, 0x10, 0x20, 0x40, 0x80}; 

const LEDMap charlie_map[30] = {
    {5,4}, {4,5}, {5,3}, {3,5}, {4,3}, {3,4}, {5,2}, {2,5}, {4,2}, {2,4}, 
    {3,2}, {2,3}, {5,1}, {1,5}, {4,1}, {1,4}, {3,1}, {1,3}, {2,1}, {1,2}, 
    {5,0}, {0,5}, {4,0}, {0,4}, {3,0}, {0,3}, {2,0}, {0,2}, {1,0}, {0,1}  
};

volatile uint8_t current_mode = 0;          
volatile uint8_t mode_changed = 0;          
volatile unsigned long last_button_press = 0;

ISR(PORTB_PORT_vect) {
    if (PORTB.INTFLAGS & PIN2_bm) {
        unsigned long now = millis();
        if (now - last_button_press > 250) {
            current_mode = (current_mode + 1) % 3; 
            mode_changed = 1;                     
            last_button_press = now;       
        }
        PORTB.INTFLAGS = PIN2_bm; 
    }
}

void uart_send(char c) {
    uint8_t sreg = SREG;
    cli(); 
    PORTB.OUTCLR = PIN3_bm;
    _delay_us(104);
    for (uint8_t i = 0; i < 8; i++) {
        if (c & (1 << i)) PORTB.OUTSET = PIN3_bm;
        else PORTB.OUTCLR = PIN3_bm;
        _delay_us(104);
    }
    PORTB.OUTSET = PIN3_bm;
    _delay_us(104);
    SREG = sreg; 
}

void uart_print_uint(uint16_t n) {
    char buf[6];
    int8_t i = 0;
    if (n == 0) { uart_send('0'); return; }
    while (n > 0) { buf[i++] = (n % 10) + '0'; n /= 10; }
    while (i > 0) { uart_send(buf[--i]); }
}

void uart_print_current_1dp(uint16_t ma_x10) {
    uart_print_uint(ma_x10 / 10);
    uart_send('.');
    uart_print_uint(ma_x10 % 10);
}

void uart_print_P(const char* str) {
    char c;
    while ((c = pgm_read_byte(str++))) { 
        uart_send(c);
        _delay_us(150); 
    }
}

uint8_t get_cal_val(uint8_t idx) { return calibration_table[idx]; }

void get_led_map(uint8_t idx, LEDMap* map) {
    map->hi = charlie_map[idx].hi;
    map->lo = charlie_map[idx].lo;
}

void set_hardware_led(uint8_t num) {
    PORTA.DIRCLR = 0xFC; 
    PORTA.OUTCLR = 0xFC; 
    if (num < 1 || num > 30) return; 
    LEDMap pair;
    get_led_map(num - 1, &pair);
    PORTA.DIRSET = led_pin_masks[pair.hi] | led_pin_masks[pair.lo]; 
    PORTA.OUTSET = led_pin_masks[pair.hi]; 
}

uint8_t leds_share_pins(uint8_t led1, uint8_t led2) {
    if (led1 < 1 || led1 > 30 || led2 < 1 || led2 > 30) return 1;
    LEDMap map1, map2;
    get_led_map(led1 - 1, &map1);
    get_led_map(led2 - 1, &map2);
    return (map1.hi == map2.hi || map1.hi == map2.lo || map1.lo == map2.hi || map1.lo == map2.lo);
}

uint8_t find_reference_led(uint8_t test_led) {
    for (uint8_t i = 0; i < 5; i++) {
        uint8_t ref = reference_leds[i];
        if (ref < 1 || ref > 30) continue;
        if (ref == test_led || leds_share_pins(test_led, ref)) continue; 
        return ref; 
    }
    return 0; 
}

__attribute__((noinline)) uint8_t select_single_channel_leds(LEDPair channel_leds[MAX_GROUP_LEDS], const LEDPair all_groups[NUM_GROUPS][MAX_GROUP_LEDS]) {
    uint8_t count = 0;
    uint8_t attempts = 0;
    for (uint8_t i = 0; i < MAX_GROUP_LEDS; i++) channel_leds[i].num = 0;

    while (count < MAX_GROUP_LEDS && attempts < 25) {
        uint8_t led = ((uint8_t)rand() % 30) + 1;
        if (led == 25) { attempts++; continue; }

        uint8_t conflict = 0;
        for (uint8_t i = 0; i < count; i++) {
            if (leds_share_pins(led, channel_leds[i].num)) { conflict = 1; break; }
        }
        if (!conflict && all_groups != NULL) {
            for (uint8_t og = 0; og < NUM_GROUPS; og++) {
                for (uint8_t i = 0; i < MAX_GROUP_LEDS; i++) {
                    if (all_groups[og][i].num > 0 && leds_share_pins(led, all_groups[og][i].num)) {
                        conflict = 1;
                        break;
                    }
                }
                if (conflict) break;
            }
        }

        if (!conflict) {
            channel_leds[count].num = led;
            channel_leds[count].level = scale_pwm_val(PWM_MAX, get_cal_val(led - 1));
            count++;
            attempts = 0;
        } else {
            attempts++;
        }
    }
    return count;
}

// ============================================================================
// UNIFIED ADC READING ROUTINE
// Handles configuration, reference selection, pin mapping, stabilization, 
// and raw conversion all in one place.
// ============================================================================
uint16_t read_adc_channel_raw(uint8_t mux_channel, uint16_t stabilization_delay_us) {
    // 1. Disable ADC to safely reconfigure
    ADC0.CTRLA = 0;
    
    // 2. Configure 4.34V internal reference and clock prescaler
    VREF.CTRLA = VREF_ADC0REFSEL_4V34_gc;    
    ADC0.CTRLC = ADC_PRESC_DIV16_gc | ADC_REFSEL_INTREF_gc;  
    
    // 3. Enable ADC
    ADC0.CTRLA = ADC_ENABLE_bm;            
    
    // 4. Configure requested MUX channel and ensure input buffer control
    if (mux_channel == ADC_MUXPOS_AIN10_gc) {
        PORTB.PIN1CTRL &= ~PORT_ISC_gm;
        PORTB.PIN1CTRL |= PORT_ISC_INPUT_DISABLE_gc;
        PORTB.DIRCLR = PIN1_bm; 
    } else if (mux_channel == ADC_MUXPOS_AIN1_gc) {
        PORTA.PIN3CTRL &= ~PORT_ISC_gm;
        PORTA.PIN3CTRL |= PORT_ISC_INPUT_DISABLE_gc;
        PORTA.DIRCLR = PIN3_bm; 
    }
    
    ADC0.MUXPOS = mux_channel;      
    
    // 5. Wait for user-configurable stabilization time
    if (stabilization_delay_us > 0) {
        delayMicroseconds(stabilization_delay_us);
    }
    
    // 6. Perform conversion
    ADC0.INTFLAGS = ADC_RESRDY_bm;
    ADC0.COMMAND = ADC_STCONV_bm;
    while (!(ADC0.INTFLAGS & ADC_RESRDY_bm));
    return ADC0.RES;
}
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

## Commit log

2026-08-31 Initial commit of PCB files
    [CSS-1210TB.SchLib, CSS-1210TB.stp, CSS1210TB.PcbLib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]
2026-09-02 fixes to sleep cycle to allow proper timing during deep sleep plus README for test software
    [Ornament_production_1.ino]
2026-09-03 power usage optimizations and clock frequency change to 8MHz instead of the default 20MHz
2026-09-03 power optimizations and documentation updates
2026-09-08 PCB updates to fix current sense amplifier layout and complete BOM
    [Ornament-B_Cu.gbr, Ornament-B_Mask.gbr, Ornament-B_Paste.gbr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]

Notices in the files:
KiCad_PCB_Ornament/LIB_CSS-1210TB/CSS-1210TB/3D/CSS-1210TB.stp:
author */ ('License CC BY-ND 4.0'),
